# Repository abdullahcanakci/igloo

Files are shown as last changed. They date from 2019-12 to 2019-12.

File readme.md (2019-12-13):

# Igloo

Igloo is a home automation system designed to be easy to use with respect to privacy. 

There will be single hub, that applicable devices can connect, this way, I only need to create a web server to handle "User Interaction" on the hub, and it will pass down relevant data to controllers. This way I don't have to implement so much in ESP12's constraints. This has significant positives:

- Only need to create one web app to handle multi devices.
- Ease of adding and removing devices to system
  - Old way, I have to add a device to a network and set it up, and use it alone. This way, a newly added device can search the network for a compliant device and set up a connection and set the device up. After we can manage the controller device with the unified web app.
- Ease of extensibility. 
  - Host system can be updated to handle more types of devices.
  - Host can be changed with a compliant system.
  - Host can implement third party home automation systems.
- Can update controller systems through air? Should be possible, have seen it, need to check how to implement it.

# Devices

- [Aurora](aurora/readme.md)

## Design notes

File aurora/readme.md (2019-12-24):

# Preface

I have one of those led strips with a colorful remote to control it. Most people have them, they are cheap, they are easy to install and most important of all abundant.

If I have to find a problem with them, it would be their horrendous controls. They have all the colors needed for full spectrum color creation, but their control circuitry only allows about 20 colors and 10 brightness settings.

I would like to have a controller with precise color control,  multiple modes to use and somewhat smart so it can act on predefined triggers.

Aim of the Aurora project is to create a led strip controller.

[Workspace Set-up](workspace.md)

## Requirements

1. High color range.
2. Multiple modes to use.
3. Actions by predefined triggers.
4. Integrated or solo use.
5. Preferably remote controlled.

### Led Control

Most of the generic led strips I have found contains RGB sink channels and 1 common VCC one. These are generally powered by 12V dedicated power supplies. There are some 4 color strips which includes white but they are not really common.

Each color channel will be controlled by a dedicated mosfet circuitry. These circuits will be driven by a micro controller in PWM achieve fine grained control.

#### Brightness

Controlling brightness of a led emitting diode is hard. On a led display a backlight is used to illuminate the colored substrate. If you want to control it's brightness you reduce the duty cycle of backlight to achieve different brightness levels. In light emitting diodes each color led is producing it's own light and reducing brightness by clamping duty cycle of  said led will create different color ranges on different brightness levels which can be observed on devices using OLED technology.

There are 2 different ways to tackle this problem. Making the brightness a logarithmic curve, so color range loss will be less visible is easier one but also the problem will still persist. Other one is, defining 3 color channels as 1 channel and controlling the duty cycle of this main channel. In the end we will achieve better color accuracy.

#### Coloring

Creating a color mix of 3 different light sources is easy with controlling duty cycle of each color channel.

### Modes

Lightning modes available on a commercial device at best is lacking. Strobe, fade, flash and few more. They are all uncomfortable. I don't really know if a good mode can be found to implement.

#### Fade

After the user changed the color, displayed color will be fade to the new color.

### Trigger

Led drivers are dumb as in they do not have a memory to act on and can not act upon triggers from outside. 

Outside trigger can be a set time where the device turns on. A loop it can run through or something that does not come as easily.

### Remote 

Although having a network connection is great we can't be certain a networking device will be available, this reason if we can integrate IR receiver so it can controllable by remotes would be good.

I have checked [Arduino-IRremote](https://github.com/z3t0/Arduino-IRremote) library to understand how they handle IR signal receiving and conversion. It uses an interrupt with 50 nanosecond interval. I don't think I can afford that with RTOS, network and led switching. I will check if it can be done but it does not looks promising.

### Integration

I am designing this device to be used within a larger ecosystem. 

To use within the ecosystem, a host device must be available on the network to connect.

## Hardware

- ESP12 is a micro controller with network integration and high storage space. 
- IRLML0030
  - SOT23 - so small
  - Rds<sub>on_normalized</sub> = 33mΩ at 10.8V gate voltage with 5 Amp current
  - 0.8W power dissipation @ 5Amp current
  - 0.42$ per piece
- BC807 - BC817, as mosfet driver circuit.
  - Widely available
  - 0.10$ per 20/25 piece
- 6mm tactile buttons for interaction
- 100-470 uF elec cap
- DC jack for power input

- Terminal strip or pin headers for led strip connections.
- required surface mount capacitors and resistor.

PCB with 2 layers preferably smaller than 50x60mm. Square?

# Application

Before any software development I would like to design the device schematic to be finished. Reason is I would like to test every step of software as I developed.

## Hardware Design

1. Power and led connections should be on the same side.
2. Buttons should be on the opposite side of the power connection.
3. Preferably screw points around connection points.
4. Programming connection.
5. Large ground areas around mosfets.

Driving mosfets with micro controller pins are not a wise move. With high current and slow gate charge times, switching losses would be high. If I use 3 transistors per channel I can drive mosfets with high current at 10.8V.

Power dissipation is fine at 10.8V gate voltage, 5.2A current. Resistive losses are @ 0.89W which will raise temperature to 90°C over ambient. Switching losses should be fine. By using transistors I reduced time to charge the gate capacitor. Also ESP12 will most likely run the PWM @ 200Hz which is pretty low, in this situation resistive losses will be the driving force. 

I used [this](https://www.electronicdesign.com/boards/calculate-dissipation-mosfets-high-power-supplies) website to help me with power dissipation.

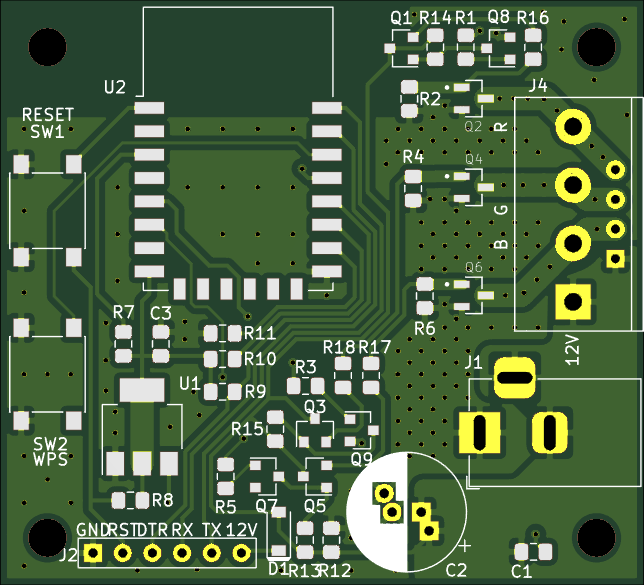
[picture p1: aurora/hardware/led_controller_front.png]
Front


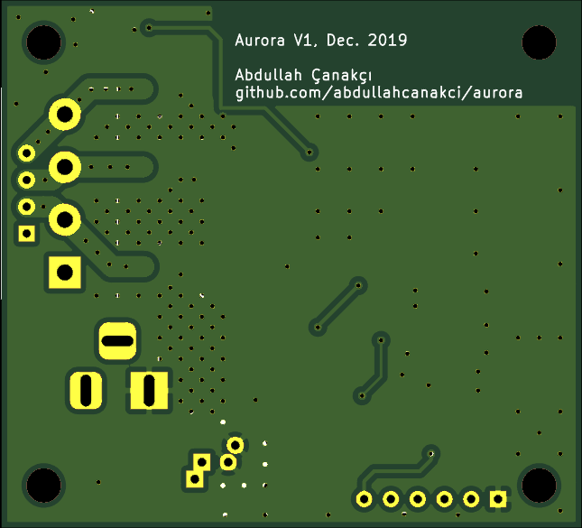
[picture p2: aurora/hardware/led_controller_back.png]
Back


# Software Requirements

2 operation modes. Slave mode and solo mode. 

Selection will be done with the FUNC button on the device. If the button is depressed on the boot sequence it will enter the solo mode, if not slave mode will initiate.

After the device boot FUNC button will have 2 different roles. Short press will toggle the light status. Holding the button will activate network settings. In network mode holding the button will start the WPS process, short pressing it will start a network interface to connect with another device to set it up. In this state the user can define network properties, and device settings. Next boot will use updated settings

Slave mode will be used with host device and only will be controlled through unified interface of host device. Aurora won't connect to the internet in this mode, will pull time information from host device.

Solo mode will need a driver application or mqqt server to handle it.

Requirements:

1. Boot sequence state machine.
2. Time based interrupts.
3. Led control routine.
4. Led control interface.
5. Led control web interface.
6. Solo mode web user interface
7. Slave mode interface

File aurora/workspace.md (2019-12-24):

This document is created to help with workspace setup.

This document is created and tested on ``` Ubuntu 19.10 with kernel 5.3.0-24-generic ```.

Prerequisites

```
sudo apt install python python-pip git
```

Add the user to dialout group, so it has permission to use serial devices. (No need to change $USER)

```
sudo usermod -a -G dialout $USER
```

Create a folder on your home directory to put toolchaing and SDK.

```
mkdir ~/esp
cd ~/esp
git clone https://github.com/espressif/ESP8266_RTOS_SDK.git
```
Go and download latest toolchain for Linux(64) from [github](https://github.com/espressif/ESP8266_RTOS_SDK).

Extract xtensa-lx106-elf to ~/esp

From command line 

```bash
tar -xzf /Downloaded_File/ -C ~/esp/
or
cd ~/esp 
tar -xzf /path/to/downloaded/file/
```

Need to update PATH to be able to use newly installed tools.

```
nano ~/.profile
```

Add these to the bottom. (No need to change $HOME)

```bash
export PATH="$PATH:$HOME/esp/xtensa-lx106-elf/bin"
export IDF_PATH=$HOME/esp/ESP8266_RTOS_SDK
export PATH="$PATH:$HOME/.local/bin"
```

Log out or restart your computer.

Toolchain uses esptool.py to flash the device but it needs some pip packages.

```
python -m pip install --user -r ~/esp/ESP8266_RTOS_SDK/requirements.txt
```

You are all done.

To test your tool-chain.

```bash
mkdir esp_test
cp -r ~/esp/ESP8266_RTOS_SDK/examples/get-started/hello-world ~/esp_test
cd ~/esp_test/hello_world
```

Plug in your dev board or serial flash board.

```
dmesg | grep tty
```

will produce connected serial devices like below. I'm using a cp2102 serial flash chip. If you are using ch340 or ftdi look for them. Note the connected port ```ttyUSB0```

```bash
[    0.143973] printk: console [tty0] enabled
[16179.376136] usb 1-1: cp210x converter now attached to ttyUSB0
```

You should be in the hello_world directory right now.

Run below command

```bash
make menuconfig
```

Select "Serial Flasher Config" and check if Default serial port is the same as you noted if not fix it. You may change "Flash size" too. Exit and save the config.

Now everything should be fine to run the device.

```bash
make all
```

If any error produced by this, fix before continuing.

```bash
make flash
```

If you encounter any permission errors, enter ```groups``` into terminal and check if you are included in "dialout" group. If not try adding again or check the internet.

After this your device should be flashed and running. You can run ``` make monitor``` and check if it is indeed running. It will show compile information, some system information and a countdown from 10 before restart.

```make monitor``` requires Ctrl+] combo to exit. Unfotunaly I don't have access to that combo without another modifier and it prevents exiting. I modified idf_monitor inside the SDK with another combo but didn't work for some reason. To reflash the device while in the monitor press```Ctrl+T -> Ctrl+F```. It will flash the device and start monitoring it.

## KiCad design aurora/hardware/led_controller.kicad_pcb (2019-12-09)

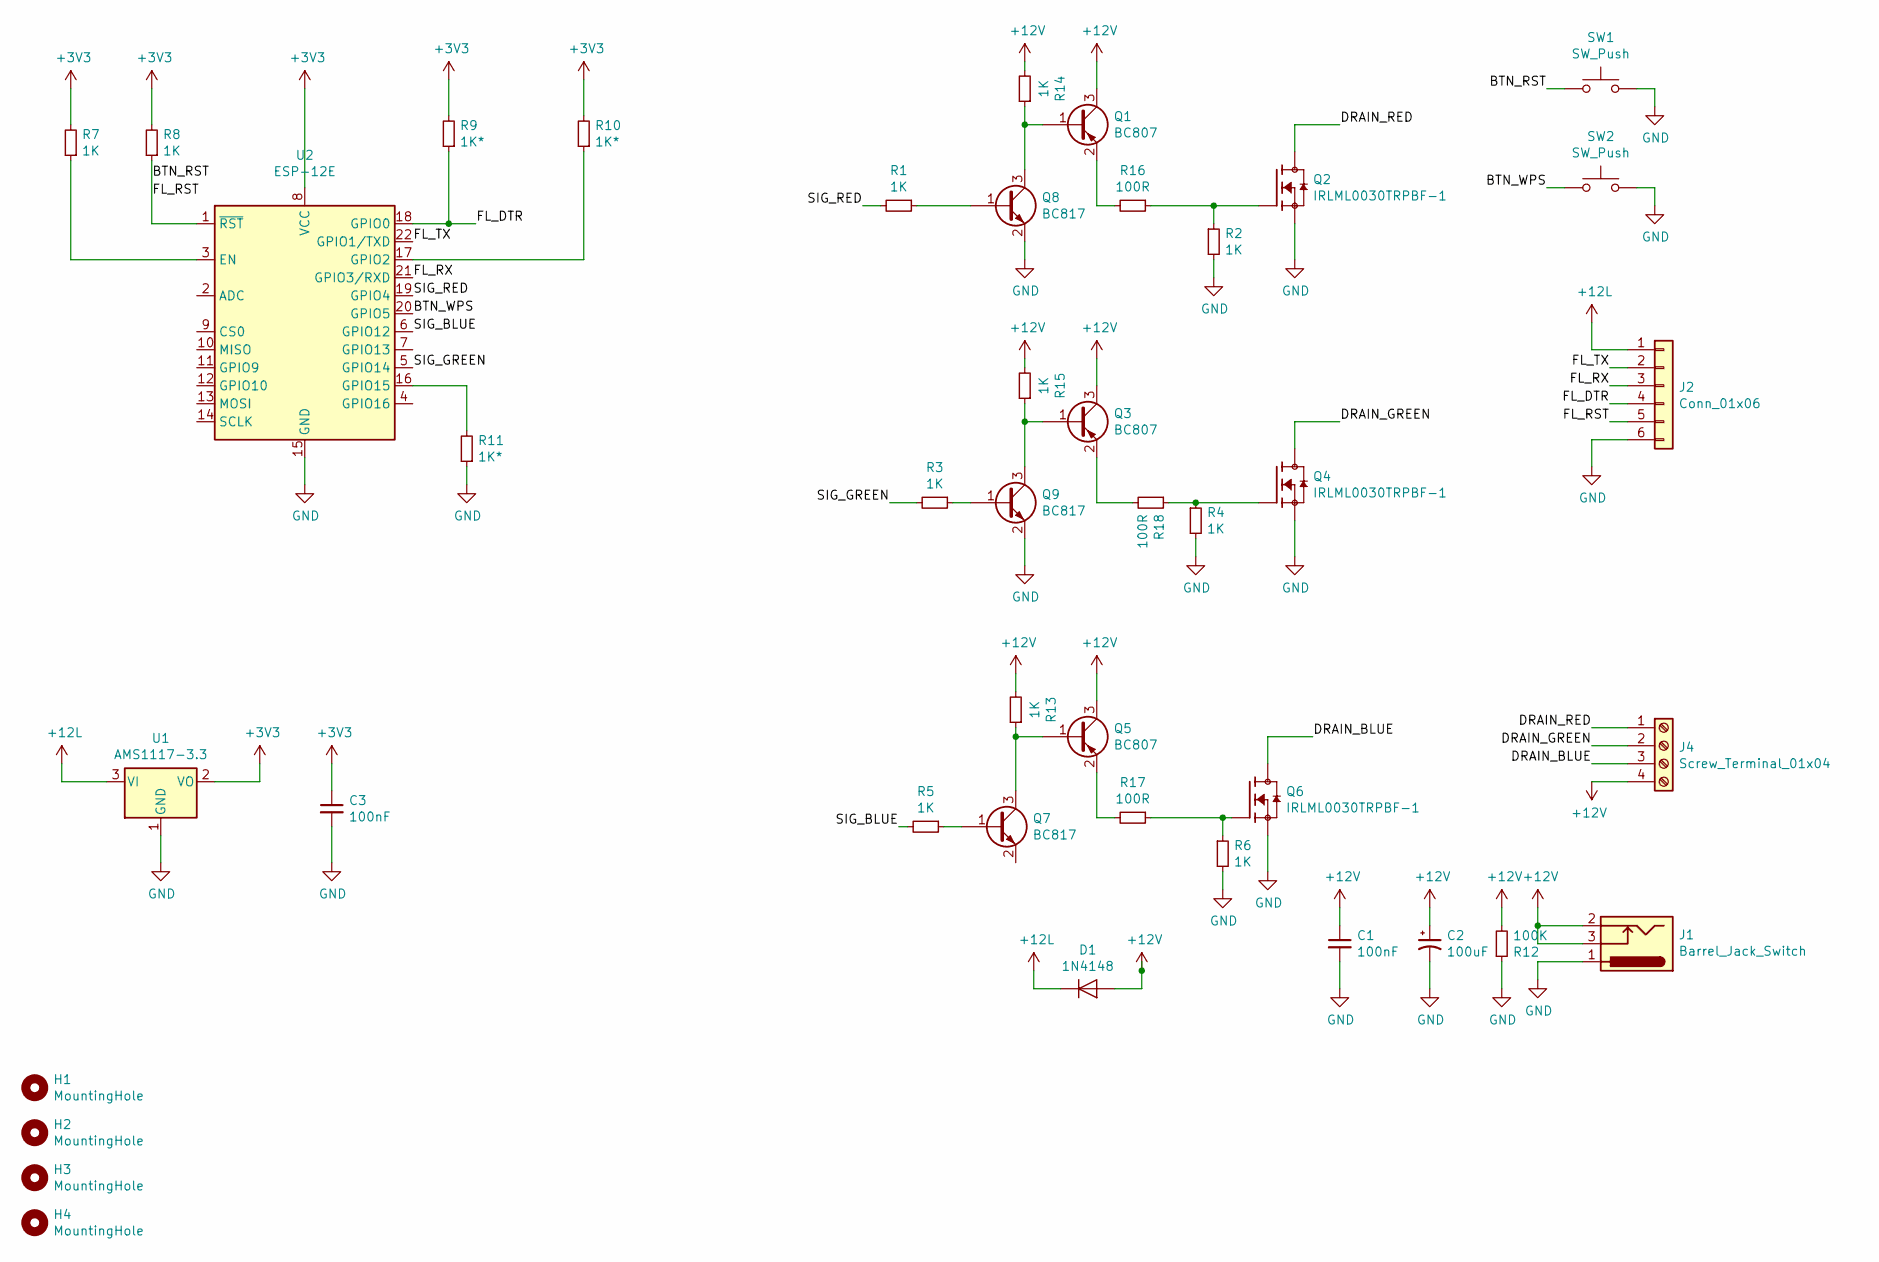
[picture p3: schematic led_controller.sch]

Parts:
C1, C3: 100nF; C_0805_2012Metric_Pad1.15x1.40mm_HandSolder
C2: 100uF; CP_Radial_D10.0mm_P2.50mm_P5.00mm
D1: 1N4148; D_SOD-123
H1, H2, H3, H4: MountingHole; MountingHole_3.2mm_M3
J1: Barrel_Jack_Switch; BarrelJack_Horizontal
J2: Conn_01x06; Header_Programming
J4: Screw_Terminal_01x04; connector_led
Q1, Q3, Q5: BC807; SOT-23
Q2, Q4, Q6: IRLML0030TRPBF-1; SOT95P237X112-3N
Q7, Q8, Q9: BC817; SOT-23
R1, R2, R3, R4, R5, R6, R7, R8, R13, R14, R15: 1K; R_0805_2012Metric_Pad1.15x1.40mm_HandSolder
R9, R10, R11: 1K*; R_0805_2012Metric_Pad1.15x1.40mm_HandSolder
R12: 100K; R_0805_2012Metric_Pad1.15x1.40mm_HandSolder
R16, R17, R18: 100R; R_0805_2012Metric_Pad1.15x1.40mm_HandSolder
SW1, SW2: SW_Push; SW_Push_1P1T_NO_6x6mm_H9.5mm
U1: AMS1117-3.3; SOT-223-3_TabPin2
U2: ESP-12E

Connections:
+3V3: C3.1, R7.2, R8.2, R9.2, R10.2, U1.2 (VO), U2.8 (VCC)
+12L: D1.1 (K), J2.1, U1.3 (VI)
+12V: C1.1, C2.1, D1.2 (A), J1.2, J1.3, J4.4, Q1.3 (C), Q3.3 (C), Q5.3 (C), R12.2, R13.2, R14.2, R15.2
/BTN_RST: J2.5, R8.1, SW1.1, U2.1 (~RST)
/BTN_WPS: SW2.1, U2.20 (GPIO5)
/DRAIN_BLUE: J4.3, Q6.3 (D)
/DRAIN_GREEN: J4.2, Q4.3 (D)
/DRAIN_RED: J4.1, Q2.3 (D)
/FL_DTR: J2.4, R9.1, U2.18 (GPIO0)
/FL_RX: J2.3, U2.21 (GPIO3/RXD)
/FL_TX: J2.2, U2.22 (GPIO1/TXD)
/SIG_BLUE: R5.2, U2.6 (GPIO12)
/SIG_GREEN: R3.2, U2.5 (GPIO14)
/SIG_RED: R1.2, U2.19 (GPIO4)
GND: C1.2, C2.2, C3.2, J1.1, J2.6, Q2.2 (S), Q4.2 (S), Q6.2 (S), Q8.2 (E), Q9.2 (E), R2.2, R4.2, R6.2, R11.1, R12.1, SW1.2, SW2.2, U1.1 (GND), U2.15 (GND)
unnamed: Q1.1 (B), Q8.3 (C), R14.1
unnamed: Q1.2 (E), R16.2
unnamed: Q2.1 (G), R2.1, R16.1
unnamed: Q3.1 (B), Q9.3 (C), R15.1
unnamed: Q3.2 (E), R18.2
unnamed: Q4.1 (G), R4.1, R18.1
unnamed: Q5.1 (B), Q7.3 (C), R13.1
unnamed: Q5.2 (E), R17.2
unnamed: Q6.1 (G), R6.1, R17.1
unnamed: Q7.1 (B), R5.1
unnamed: Q8.1 (B), R1.1
unnamed: Q9.1 (B), R3.1
unnamed: R7.1, U2.3 (EN)
unnamed: R10.1, U2.17 (GPIO2)
unnamed: R11.2, U2.16 (GPIO15)

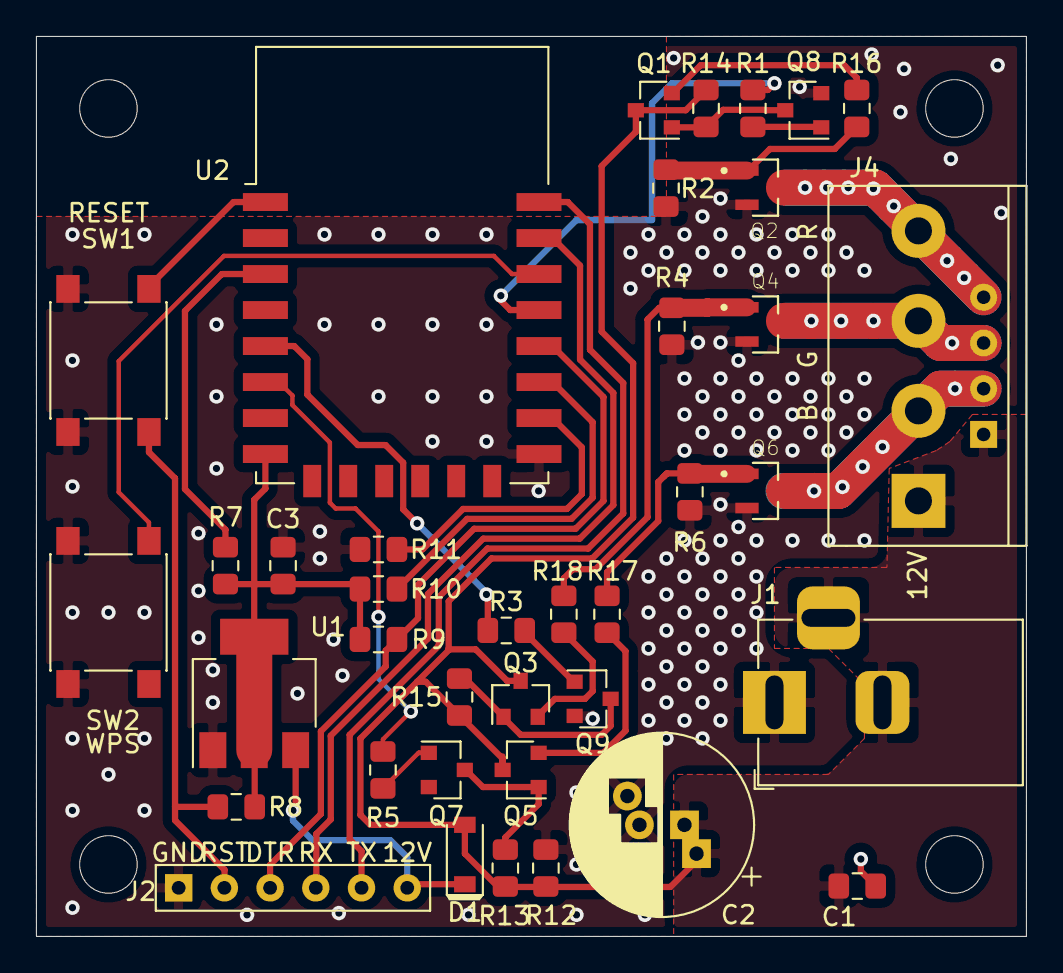
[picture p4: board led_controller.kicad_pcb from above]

Board: 2 copper layers, 55.0 x 50.0 mm, 42 parts (0 on the bottom side), 30 nets.

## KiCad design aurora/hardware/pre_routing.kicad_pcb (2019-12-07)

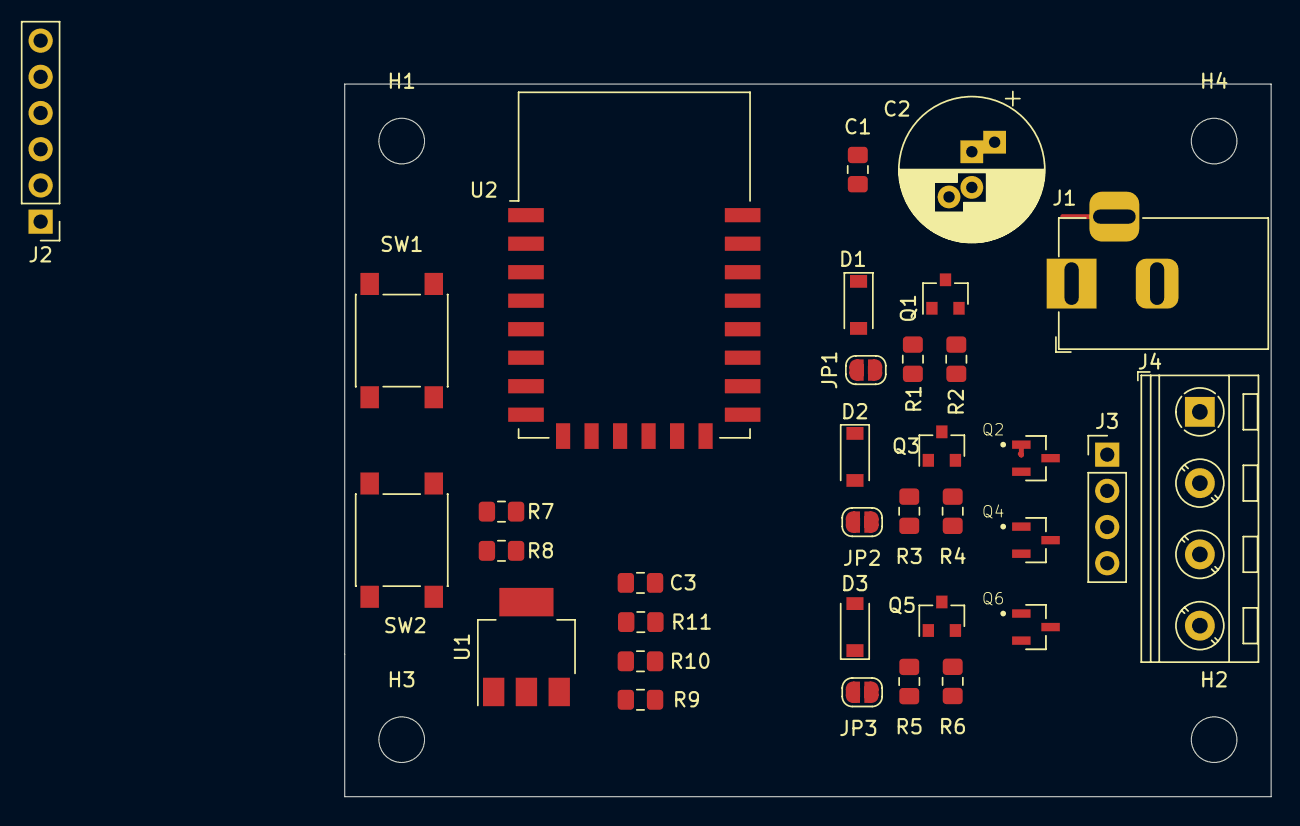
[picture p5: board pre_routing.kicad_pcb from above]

Board: 2 copper layers, 65.0 x 50.0 mm, 38 parts (0 on the bottom side), 23 nets.

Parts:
C1, C3: 100nF; C_0805_2012Metric_Pad1.15x1.40mm_HandSolder
C2: 100uF; CP_Radial_D10.0mm_P2.50mm_P5.00mm
D1, D2, D3: 1N4148W; D_SOD-123
H1, H2, H3, H4: MountingHole; MountingHole_3.2mm_M3
J1: Barrel_Jack_Switch; BarrelJack_Horizontal
J2: Conn_01x06; PinHeader_1x06_P2.54mm_Vertical
J3: Conn_01x04; PinHeader_1x04_P2.54mm_Vertical
J4: Screw_Terminal_01x04; TerminalBlock_RND_205-00047_1x04_P5.00mm_Horizontal
JP1: Red; SolderJumper-2_P1.3mm_Open_RoundedPad1.0x1.5mm
JP2: Green; SolderJumper-2_P1.3mm_Open_RoundedPad1.0x1.5mm
JP3: Blue; SolderJumper-2_P1.3mm_Open_RoundedPad1.0x1.5mm
Q1, Q3, Q5: BC807; SOT-23
Q2, Q4, Q6: IRLML0030TRPBF-1; SOT95P237X112-3N
R1, R3, R5, R7, R8: 1K; R_0805_2012Metric_Pad1.15x1.40mm_HandSolder
R2, R4, R6: 100R; R_0805_2012Metric_Pad1.15x1.40mm_HandSolder
R9, R10, R11: 1K*; R_0805_2012Metric_Pad1.15x1.40mm_HandSolder
SW1, SW2: SW_Push; SW_Push_1P1T_NO_6x6mm_H9.5mm
U1: AMS1117-3.3; SOT-223-3_TabPin2
U2: ESP-12E

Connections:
+3V3: C3.1, R7.2, R8.2, R9.2, R10.2, U1.2, U2.8
+12V: C1.1, C2.1, J1.2, J1.3, J2.1, J3.1, J4.1, Q1.3, Q3.3, Q5.3, U1.3
/BTN_WPS: SW2.1, U2.20
/DRAIN_BLUE: J3.4, J4.4, Q6.3
/DRAIN_GREEN: J3.3, J4.3, Q4.3
/DRAIN_RED: J3.2, J4.2, Q2.3
/FL_DTR: J2.5, R9.1, U2.18
/FL_RX: J2.3, U2.21
/FL_TX: J2.4, U2.22
/SIG_BLUE: JP3.1, R5.2
/SIG_GREEN: JP2.1, R3.2
/SIG_RED: JP1.1, R1.2
GND: C1.2, C2.2, C3.2, J1.1, J2.6, Q2.2, Q4.2, Q6.2, R2.2, R4.2, R6.2, R11.1, SW1.2, SW2.2, U1.1, U2.15
unnamed: D1.1, Q1.1, R1.1
unnamed: D1.2, JP1.2, Q1.2, Q2.1, R2.1
unnamed: D2.1, Q3.1, R3.1
unnamed: D2.2, JP2.2, Q3.2, Q4.1, R4.1
unnamed: D3.1, Q5.1, R5.1
unnamed: D3.2, JP3.2, Q5.2, Q6.1, R6.1
unnamed: R7.1, U2.3
unnamed: R8.1, U2.1
unnamed: R10.1, U2.17
unnamed: R11.2, U2.16

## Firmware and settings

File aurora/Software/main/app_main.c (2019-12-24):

#include "app_main.h"

void app_main()
{
    // SET FUNC BUTTON
    gpio_config_t but_conf;
    but_conf.intr_type = GPIO_INTR_ANYEDGE;
    but_conf.mode = GPIO_MODE_INPUT;
    but_conf.pin_bit_mask = 1ULL << GPIO_BUT_FUNC;
    but_conf.pull_up_en = 1;

    gpio_config(&but_conf);

    gpio_evt_queue = xQueueCreate(10, sizeof(uint32_t));
    xTaskCreate(gpio_task, "gpio_task", 2048, NULL, 10, NULL);

    gpio_install_isr_service(0);
    gpio_isr_handler_add(GPIO_BUT_FUNC, gpio_isr_handler, (void *)GPIO_BUT_FUNC);

    // SYSTEM TIMER
    xTaskCreate(system_timer, "system_timer", 256, NULL, 11, NULL);

    // PWM SYSTEM
    pwm_init(PWM_PERIOD, pwm_duties, 3, pwm_channels);
    pwm_set_channel_invert(0);
    pwm_set_phases(pwm_phases);
    pwm_start();

    xTaskCreate(led_control_task, "led_control", 256, NULL, 10, NULL);

    nvs_flash_init(); // Needed for WIFI credentials
    esp_event_loop_init(event_handler, NULL);
    start_wifi();
}

static void debounce(int in_state)
{
    uint32_t temp = timer;
    if (func_button.state != in_state)
    {
        if (func_button.time_down - temp < 10 * 1000 / configTICK_RATE_HZ)
        {
            return;
        }
        func_button.state = in_state;
        if (func_button.state == DOWN)
        {
            func_button.time_down = temp;
        }
        else
        {
            func_button.time_up = temp;
        }
        if (func_button.state == UP && func_button.time_down != 0)
        {
            uint32_t interval = (func_button.time_up - func_button.time_down) * 1000 / configTICK_RATE_HZ;
            if (interval < 2000)
            {
                ESP_LOGI("BUTTON", "CLICK, WPS starting.");
                start_wps();
            }
            else
            {
                ESP_LOGI("BUTTON", "HOLD");
            }
            func_button.time_up = 0;
            func_button.time_down = 0;
        }
    }
}

/******************** TASKS ************************/

/**
 * freeRTOS does not have a neat system time function.
 * I need a basic one to debounce buttons.
 * timer is uint32_t which can hold about 29 days in 1ms resolution.
 */
static void system_timer(void *arg)
{
    for (;;)
    {
        timer = timer + 1;
        vTaskDelay(1);
    }
}

static void gpio_task(void *arg)
{
    uint32_t io_num;
    for (;;)
    {
        if (xQueueReceive(gpio_evt_queue, &io_num, portMAX_DELAY))
        {
            if (io_num == GPIO_BUT_FUNC)
            {
                debounce(gpio_get_level(io_num));
            }
        }
    }
}

static void led_control_task(void *arg){
    static bool toggle = false;
    for (;;)
    {
        if(toggle){
            pwm_set_duty(0, 300);
            pwm_set_duty(1, 300);
            pwm_set_duty(2, 300);
        }
        else
        {
            pwm_set_duty(0, 900);
            pwm_set_duty(1, 0);
            pwm_set_duty(2, 400);
        }
        toggle = !toggle;
        pwm_start();
        vTaskDelay(1000 * 1000 / configTICK_RATE_HZ);
    }
}
/**************ISR HANDLERS***************/

static void gpio_isr_handler(void *args)
{
    uint32_t gpio_num = (uint32_t)args;
    xQueueSendFromISR(gpio_evt_queue, &gpio_num, NULL);
}

/*************WIFI*******************/

static esp_err_t event_handler(void* ctx, system_event_t* event)
{
    const char *TAG = "WIFI_EVENT_HANDLER";
    /* For accessing reason codes in case of disconnection */
    system_event_info_t *info = &event->event_info;
    
    switch (event->event_id) {
        case SYSTEM_EVENT_STA_START:
            ESP_LOGI(TAG, "SYSTEM_EVENT_STA_START");
            esp_wifi_connect();
            break;

        case SYSTEM_EVENT_STA_GOT_IP:
            ESP_LOGI(TAG, "SYSTEM_EVENT_STA_GOT_IP");
            ESP_LOGI(TAG, "got ip:%s\n",
                     ip4addr_ntoa(&event->event_info.got_ip.ip_info.ip));
            break;

        case SYSTEM_EVENT_STA_DISCONNECTED:
            ESP_LOGI(TAG, "SYSTEM_EVENT_STA_DISCONNECTED");
            ESP_LOGE(TAG, "Disconnect reason : %d", info->disconnected.reason);
            if (info->disconnected.reason == WIFI_REASON_BASIC_RATE_NOT_SUPPORT) {
                /*Switch to 802.11 bgn mode */
                esp_wifi_set_protocol(ESP_IF_WIFI_STA, WIFI_PROTOCAL_11B | WIFI_PROTOCAL_11G | WIFI_PROTOCAL_11N);
            }
            esp_wifi_connect();
            break;

        case SYSTEM_EVENT_STA_WPS_ER_SUCCESS:
            /*point: the function esp_wifi_wps_start() only get ssid & password
             * so call the function esp_wifi_connect() here
             * */
            ESP_LOGI(TAG, "SYSTEM_EVENT_STA_WPS_ER_SUCCESS");
            esp_wifi_wps_disable();
            esp_wifi_set_storage(WIFI_STORAGE_FLASH);
            esp_wifi_connect();
            break;

        case SYSTEM_EVENT_STA_WPS_ER_FAILED:
            ESP_LOGI(TAG, "SYSTEM_EVENT_STA_WPS_ER_FAILED");
            esp_wifi_wps_disable();
            esp_wifi_wps_enable(&wps_config);
            esp_wifi_wps_start(0);
            break;

        case SYSTEM_EVENT_STA_WPS_ER_TIMEOUT:
            ESP_LOGI(TAG, "SYSTEM_EVENT_STA_WPS_ER_TIMEOUT");
            esp_wifi_wps_disable();
            esp_wifi_wps_enable(&wps_config);
            esp_wifi_wps_start(0);
            break;

        case SYSTEM_EVENT_STA_WPS_ER_PIN:
            ESP_LOGI(TAG, "SYSTEM_EVENT_STA_WPS_ER_PIN");
            break;

        default:
            break;
    }

    return ESP_OK;
}

static void start_wps(void){
    esp_wifi_disconnect();

    tcpip_adapter_init();
    wifi_init_config_t cfg = WIFI_INIT_CONFIG_DEFAULT();

    esp_wifi_init(&cfg);
    esp_wifi_set_mode(WIFI_MODE_STA);
    esp_wifi_start();

    ESP_LOGI("WPS", "start wps...");

    esp_wifi_wps_enable(&wps_config);
    esp_wifi_wps_start(0);
}

static void start_wifi(void){
    tcpip_adapter_init();
    wifi_init_config_t cfg = WIFI_INIT_CONFIG_DEFAULT();

    esp_wifi_init(&cfg);
    esp_wifi_start();
    esp_wifi_connect();
}

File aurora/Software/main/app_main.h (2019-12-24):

#ifndef APP_MAIN
#define APP_MAIN


#include <stdint.h>

#include "freertos/FreeRTOS.h"
#include "freertos/task.h"
#include "freertos/event_groups.h"
#include "freertos/queue.h"
#include "driver/gpio.h"
#include "driver/pwm.h"
#include "esp_event_loop.h"
#include "esp_log.h"
#include "esp_wifi.h"
#include "esp_wps.h"
#include "nvs_flash.h"

#define GPIO_BUT_FUNC 5
#define GPIO_LED_CH1 4  //RED
#define GPIO_LED_CH2 12 //BLUE
#define GPIO_LED_CH3 14 //GREEN
#define PWM_PERIOD 1000 //PWM period in ms

static esp_wps_config_t wps_config = WPS_CONFIG_INIT_DEFAULT(WPS_TYPE_PBC);

static xQueueHandle gpio_evt_queue = NULL;

const uint32_t pwm_channels[3] = {
  GPIO_LED_CH1,
  GPIO_LED_CH2,
  GPIO_LED_CH3
};

uint32_t pwm_duties[3] = {
  500, 500, 500
};

int16_t pwm_phases[3] = {
  -120, 0, 120
};

typedef struct Button
{
  enum
  {
    DOWN,
    UP
  } state;
  uint32_t time_down;
  uint32_t time_up;
} Button;

Button func_button = {.state = UP, .time_down = 0, .time_up = 0};

static void debounce(int);
static void gpio_isr_handler(void *args);
static void gpio_task(void *arg);
static void system_timer(void *arg);
static void led_control_task(void *arg);
static esp_err_t event_handler(void *ctx, system_event_t *event);
static void start_wps();
static void start_wifi(void);

static uint32_t timer = 0;

#endif

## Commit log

2019-10-19 updated readme, created kicad project
    [kicad.kicad_pcb, kicad.sch]
2019-11-19 Updated readme \n\n Raspberry pi usage
2019-12-07 hardware init
    [led_controller.kicad_pcb, led_controller.sch]
2019-12-07 createad schematic and routed the pcb
    [pre_routing.kicad_pcb]
2019-12-07 Removed bakers clamps. reduced board size to 55x50 mm
    [led_controller.kicad_pcb, led_controller.sch]
2019-12-08 finished board design
    [led_controller.kicad_pcb, led_controller.sch]
2019-12-09 Modified connectors and silkscreens. Added a diode to keep capacitor from charging during flashing. Added a second layer to mosfet connector traces and stiched them to help power dissipation.
    [led_controller.kicad_pcb, led_controller.sch]
2019-12-13 Reorganized project files. Divide up readme file
    [led_controller.kicad_pcb, led_controller.sch, pre_routing.kicad_pcb]
2019-12-22 Added proto firmware for the device. Implemented a cyclic buffer for future use.
2019-12-22 Basic button debouncing and pin interrupts
2019-12-23 Button debouncing click+hold implemented. System timer added.
